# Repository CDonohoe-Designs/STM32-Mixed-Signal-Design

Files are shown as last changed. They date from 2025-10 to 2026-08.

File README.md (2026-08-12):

# STM32 Mixed-Signal Signal Generator & Analyser

I designed this project as a mixed-signal signal generation and acquisition platform based on the **STM32F103**. The system is designed to generate and analyse analogue signals over approximately **20 Hz–20 kHz** using external ADC and DAC signal paths.

The project focuses on the complete signal chain rather than the MCU alone: analogue input protection and conditioning, anti-alias filtering, ADC acquisition, DAC reconstruction filtering, analogue output buffering, bias generation, separate analogue/digital power supplies, USB-C and EMC/ESD considerations.

A major part of the work was understanding and documenting the engineering decisions behind each stage, including sampling requirements, filter design, signal biasing, noise, impedance and mixed-signal PCB architecture.

---

## Design Documentation

**[View Complete Mixed-Signal Design Report (PDF)](STM32-Mixed-Signal-Design/STM32-Mixed-Signal-Design.pdf)**

The design report is the main engineering document for this project and covers:

- System architecture and requirements
- Sampling-rate and ADC/DAC considerations
- Analogue front-end design
- Input protection and RF filtering
- Anti-alias filtering
- DAC reconstruction filtering
- Sallen-Key filter design
- Mid-supply analogue bias generation
- Separate analogue and digital power architecture
- USB-C, ESD and EMC considerations
- STM32F103 implementation
- STM32CubeIDE configuration
- Schematic design and component selection

---

## System Architecture

The system combines signal generation and signal acquisition around the STM32F103:

**Analogue Input → Protection / Filtering → Analogue Front End → ADC → STM32F103**

**STM32F103 → DAC → Reconstruction Filter / Buffer → Analogue Output**

The power architecture uses separate supplies for the analogue and digital sections, with a switching regulator used for the digital circuitry and a low-noise LDO used for the analogue circuitry.

---

## Key Design Areas

### Analogue Front End

The input signal chain includes protection, filtering, buffering and signal conditioning before the ADC.

The analogue input is biased around a mid-supply reference to allow bipolar AC signals to be processed by the single-supply analogue circuitry.

### ADC / DAC

External ADC and DAC devices provide the analogue acquisition and signal-generation paths.

The design considers:

- ADC resolution and sampling rate
- Nyquist requirements
- Input impedance
- ADC drive requirements
- Anti-alias filtering
- DAC reconstruction filtering
- Output buffering

### Power

The power architecture separates the requirements of the digital and analogue circuitry:

- Switching regulation for the digital section
- Low-noise LDO regulation for the analogue section
- Input filtering
- Decoupling
- Mid-supply analogue bias generation

### USB-C

USB-C provides the external power/interface connection.

The design includes:

- USB-C connection
- ESD protection
- Data-line filtering
- Common-mode filtering
- Power-input filtering

---

## Development Tools

- **Altium Designer** — schematic and PCB design
- **STM32CubeIDE** — STM32 configuration and embedded development
- **LTspice** — analogue and filter analysis
- **Git / GitHub** — project documentation and version control

---

## What This Project Demonstrates

This project demonstrates my approach to **mixed-signal hardware design**, particularly the interaction between analogue signal conditioning, ADC/DAC conversion, embedded processing and power architecture.

The main engineering focus is on understanding the complete signal path:

**input protection → analogue conditioning → filtering → conversion → processing → signal generation → analogue output**

rather than treating the MCU, ADC, DAC and analogue circuitry as independent blocks.

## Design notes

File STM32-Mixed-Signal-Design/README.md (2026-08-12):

# STM32 Mixed-Signal Signal Generator and Signal Analyser

This is my STM32-based mixed-signal design for a compact signal generator and signal analyser.

I designed this board to show how a small embedded system can generate analogue test signals, capture external analogue signals, and handle the practical mixed-signal design issues that come with ADCs, DACs, USB power, filtering, biasing, EMC protection and PCB layout.

My design uses an STM32 microcontroller as the main controller, with a DAC output path for signal generation and an ADC input path for signal measurement. The DAC side is used to generate low-frequency analogue waveforms, while the ADC side allows an external signal to be conditioned, filtered and sampled for analysis.

The target signal range is approximately 20 Hz to 20 kHz, so the project is aimed at low-frequency / audio-band signal work rather than high-speed RF. I included analogue front-end circuitry, anti-aliasing and reconstruction filtering, bias generation for single-supply operation, USB-C power input, ESD protection, and separate analogue/digital supply filtering.

At a high level, my design works as:

- **Signal generator:** the STM32 controls the DAC, creating an analogue output signal through a filtered output stage.
- **Signal analyser:** an external analogue signal enters through the input connector, passes through protection and analogue conditioning, and is then sampled by the ADC.
- **Mixed-signal PCB example:** the board brings together digital control, analogue signal paths, power regulation, USB, filtering, grounding and EMC considerations in one small design.

I created this project as a portfolio piece to demonstrate practical mixed-signal hardware design, from system requirements and schematic capture through to converter selection, analogue filtering, power-supply design and PCB implementation.

## Contact
**Caoilte Donohoe** · Dublin, Ireland  
Email: caoiltedonohoe@gmail.com · LinkedIn: https://www.linkedin.com/in/caoilte-donohoe-69601a40a/ · GitHub: [CDonohoe-Designs](https://github.com/CDonohoe-Designs)

---
© 2025 Caoilte Donohoe. All rights reserved.

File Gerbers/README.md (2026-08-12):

Gerber manufacturing files for STM32 Mixed-Signal Design.

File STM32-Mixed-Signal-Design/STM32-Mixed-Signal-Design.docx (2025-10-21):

STM32 Mixed Signal Design:

Description:

The purpose of the presentation is to show the design considerations for a mixed signal board. The design contains low-frequency analog and high-frequency digital design elements on a 4-layer FR4 PCB. It will also include system-level design, component selection, analogue (e.g. op-amps, filters, ADC/DAC interfaces), digital (e.g. microcontrollers, USB), and power supply (e.g. switching converter) circuitry design, simulation, and schematic capture.

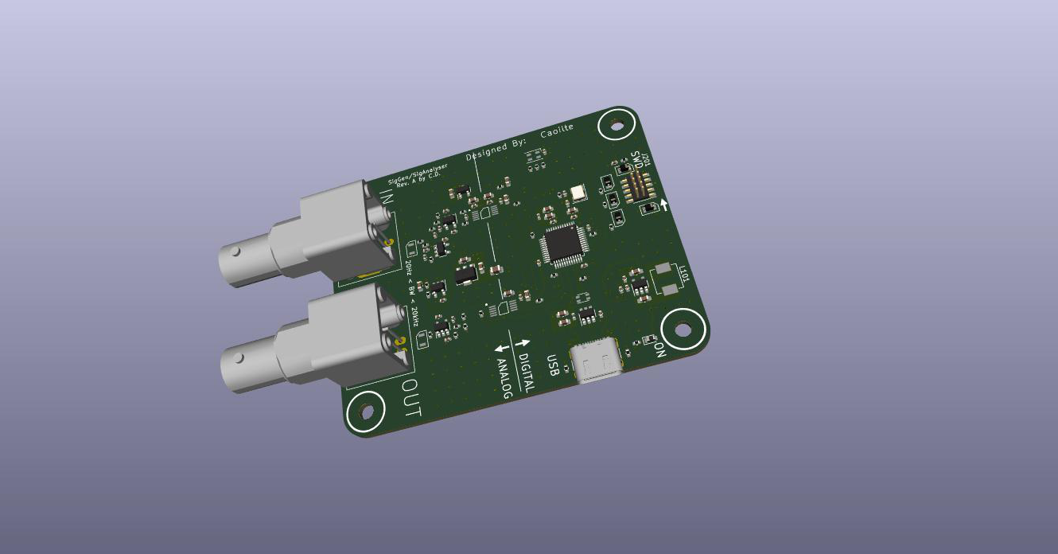
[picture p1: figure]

SYSTEM REQUIREMENTS:

USB

- The design is low-frequency (or low-bandwidth), 20 Hz to 20kHz approximately.
- The Max frequency of interest is 20kHz, so due to Nyquist, I need to sample at double the maximum frequency of interest.
- Sampling rate at least 40kHz.
- To reduce quantisation error and get accurate readings I will need an ADC with a minimum bit depth of 12.
- Single channel data-rate: I Channel x 12 bits x 40,000 samples per second (fs=40kHz) = 0.46 Mbit/s
- USB 2.0 with• FS: up to 12 Mbits/s and HS: up to 480 Mbits/s → FS is more than sufficient!
- The system is a bus-powered device only (not acting as a host), therefore far less than 500mA current consumption.
- I Choose USB Type C as it is the newest tech.

POWER SUPPLIES

Split digital and analogue supplies.

Digital: switching supply for efficiency, digital is far more tolerant of noise. This digital circuit digital draws 100s of mAs maximum.

Analog: linear (LDO) regulators for improved noise performance. Analog circuitry typically draws less current (10s of mAs maximum) → regulator efficiency is not much of an issue.

Input power from USB.

- (Very) noisy power rail → Requires adequate filtering.
- Nominally +5V. Can go as low as +4.5V → Watch out for regulator drop-out voltages!
- 150mA approx.

Analog Sections:

For ADC:

• High-impedance (>I MOhm?) input buffer with ESD protection, RF filtering.

• Anti-aliasing filter with a cut-off at (max.) half the ADC sampling rate (Nyquist limit).

For DAC:

• Low-impedance (-50 Ohm?) output buffer with ESD protection to drive loads.

• Anti-aliasing filter with a cut-off at (max.) half the DAC sampling rate (Nyquist limit).

MISCELLANEOUS

Mechanical

• PCB dimension constraints, mounting holes, connector placement, which case are we designing for (conductor?)?

Connectors

• Debugging interface, input/output connector types (SMA, BNC, etc...).

Peripherals

• LED to indicate power on, LED(s) connected to MCU for status information.

Other

• Timing (crystal frequencies, types, etc...).

• ESD protection and filtering for EMC.

• Biasing for single-supply analogue circuitry.

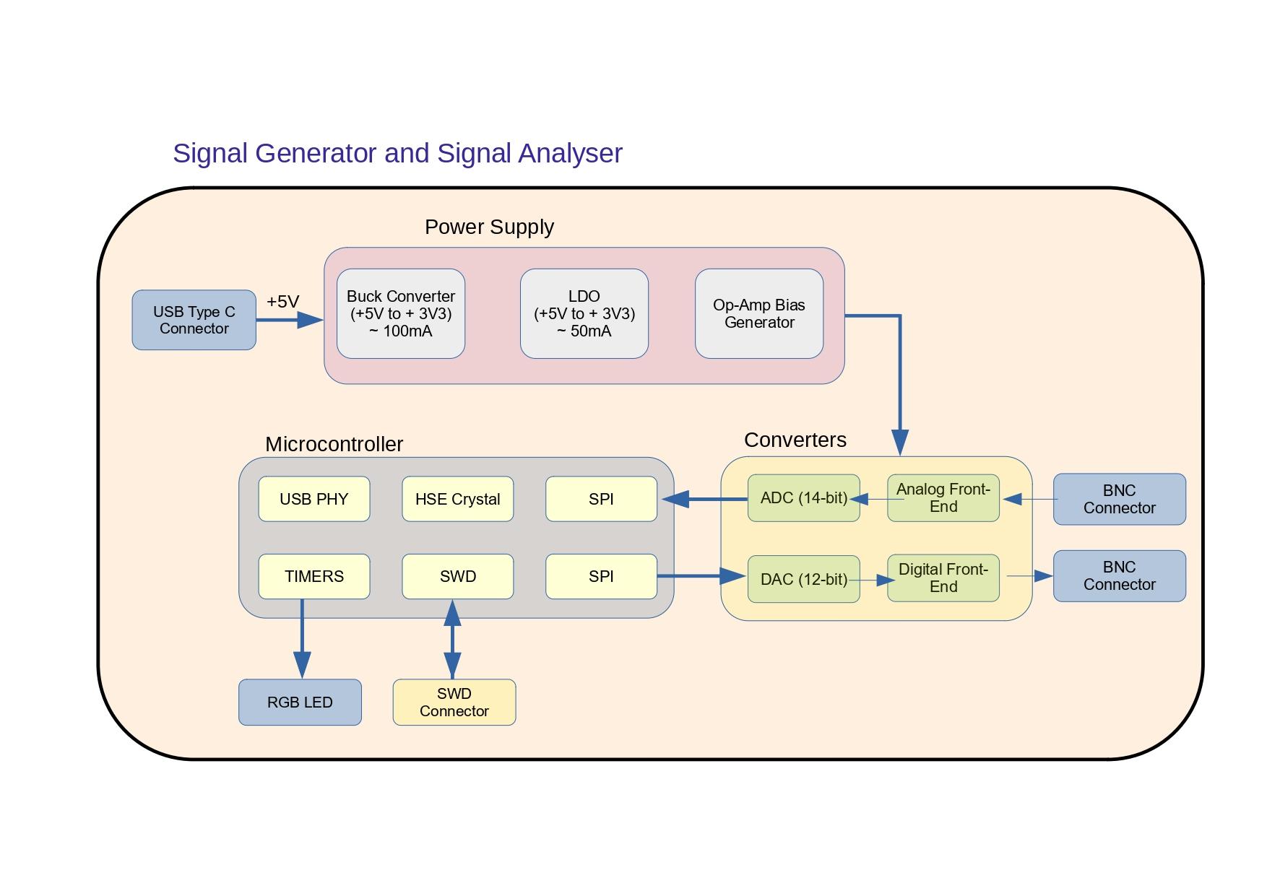
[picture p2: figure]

Schematic Capture:

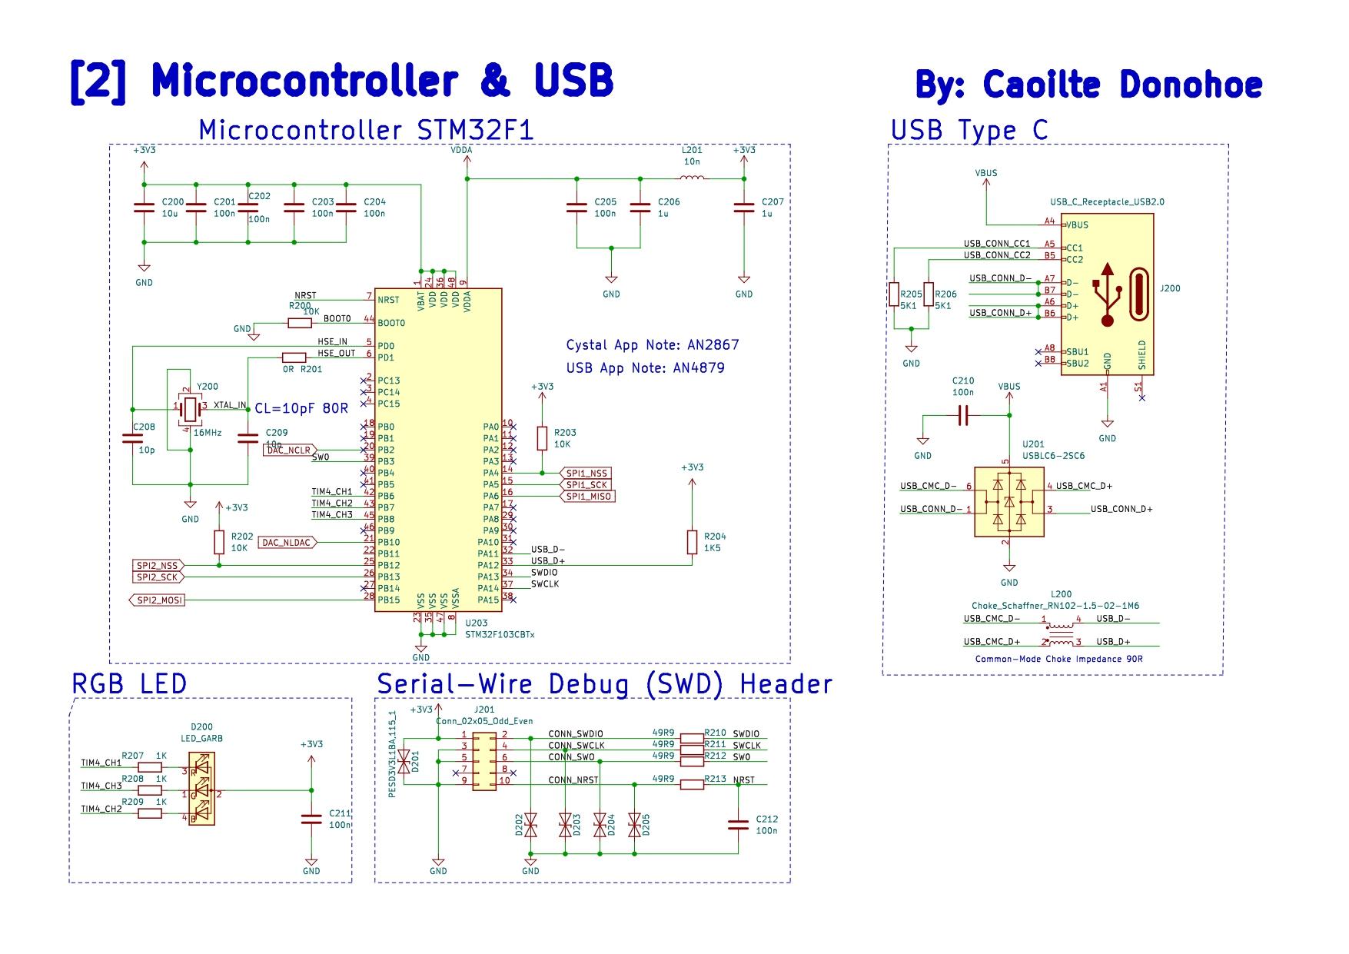
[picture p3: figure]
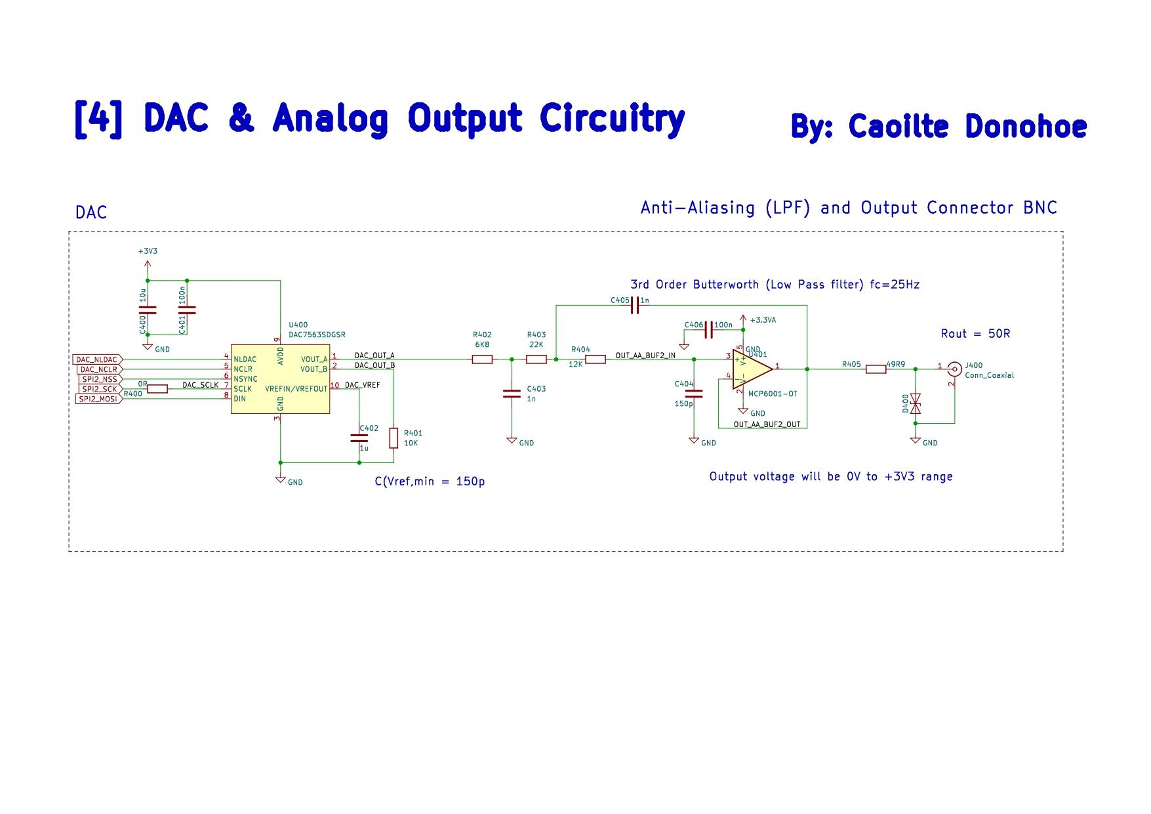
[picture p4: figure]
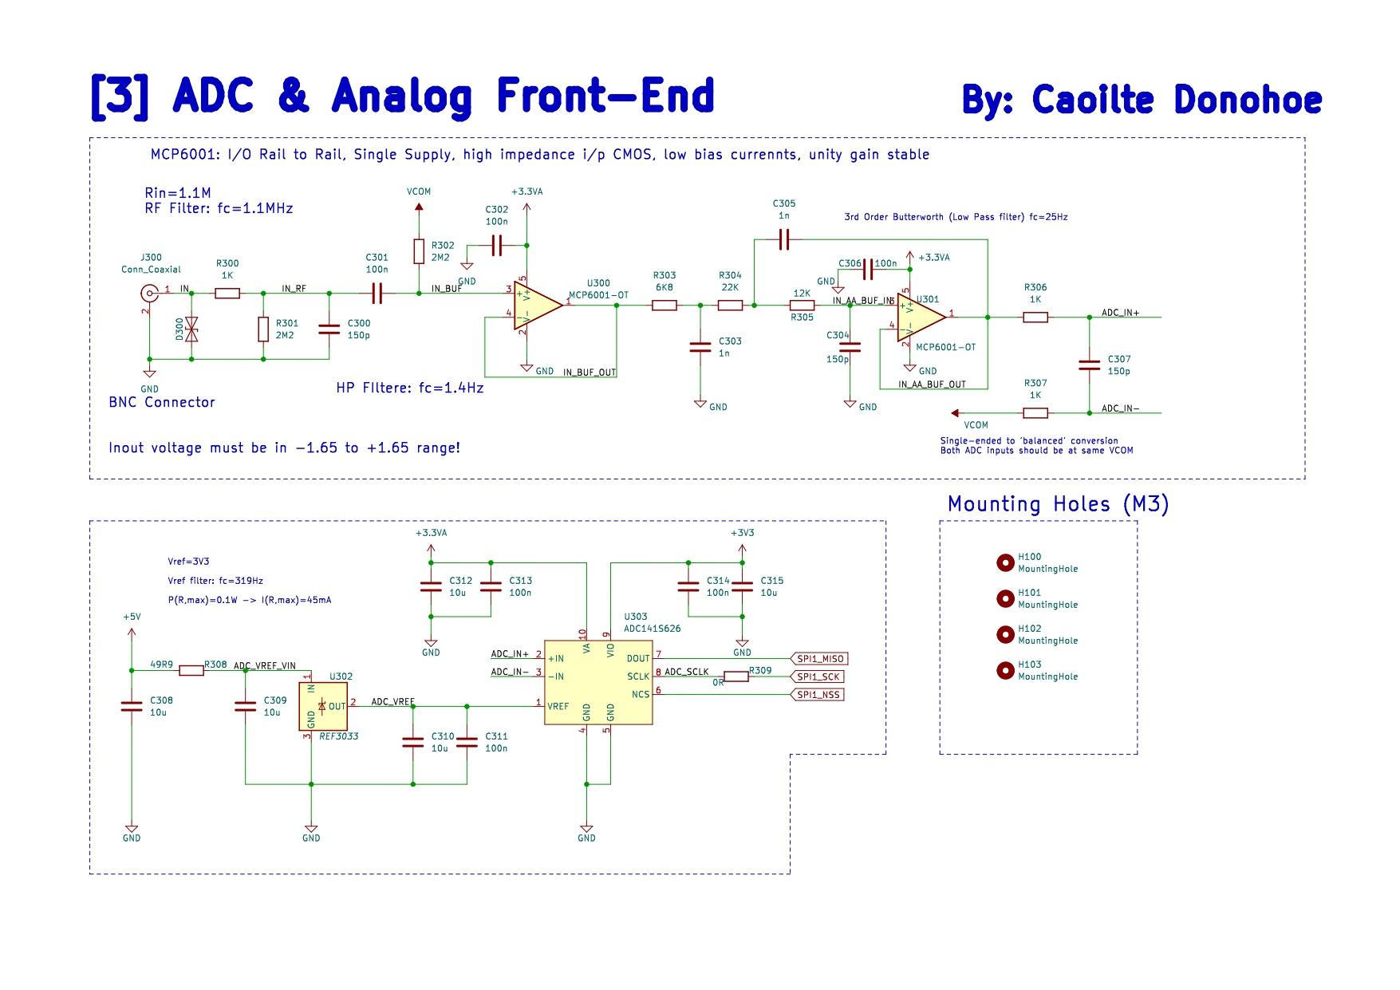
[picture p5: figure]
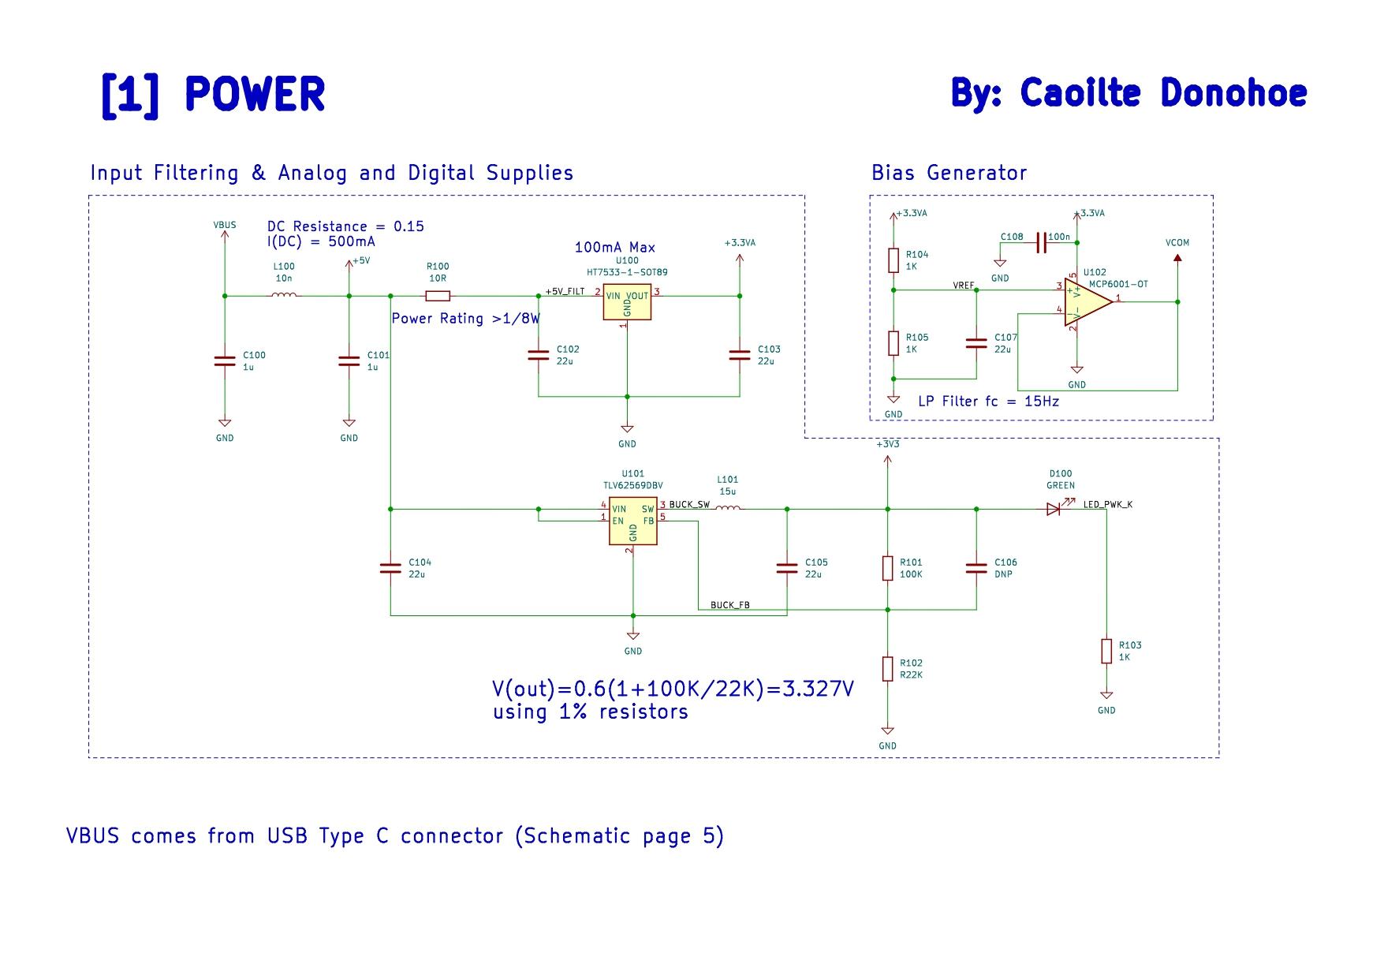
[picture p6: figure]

Schematic Design:

INPUT FILTER/LDO regulator

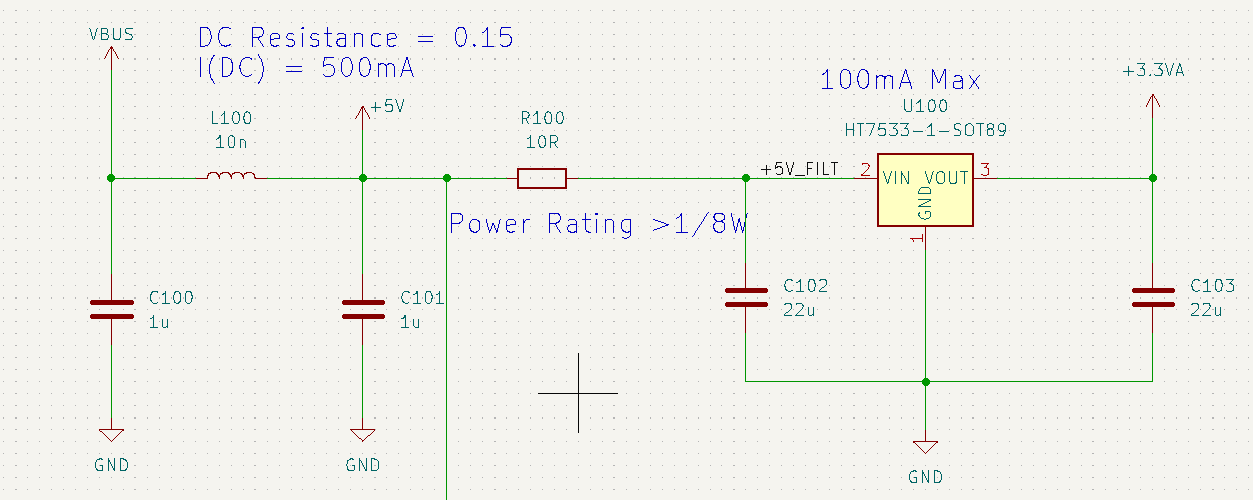
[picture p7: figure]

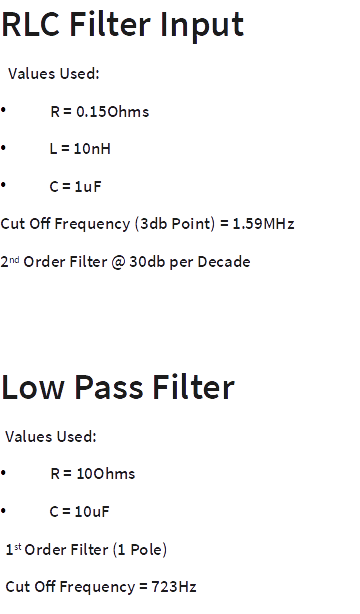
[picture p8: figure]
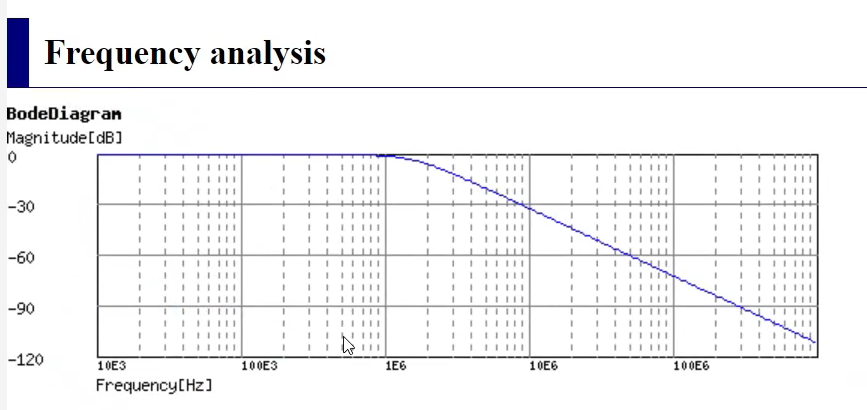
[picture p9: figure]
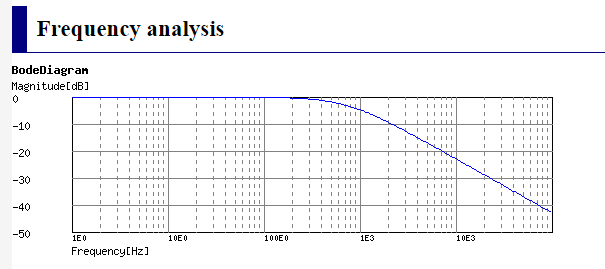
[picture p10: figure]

INPUT FILTER/LDO regulator

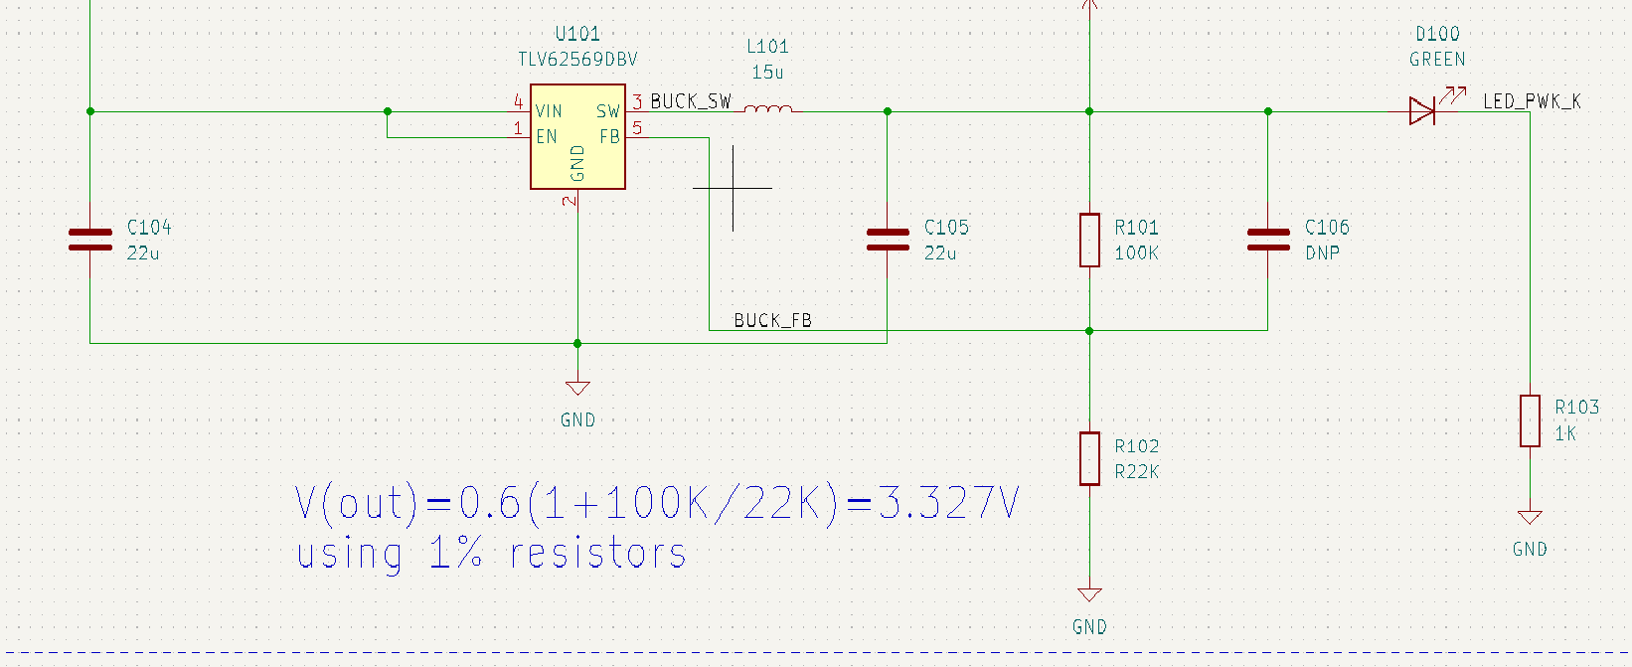
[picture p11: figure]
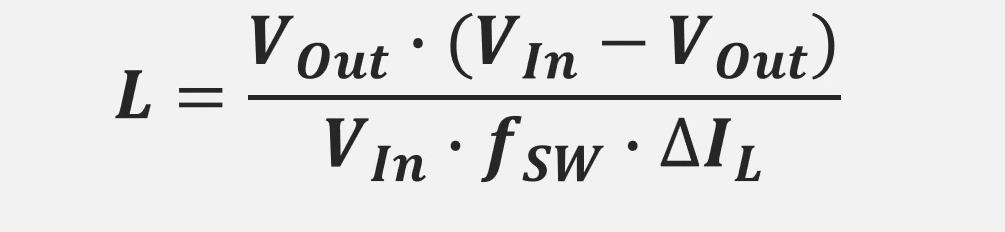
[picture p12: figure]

Inductor Calculations:

Vout = +3V3, Vin = 5V

fsw = 1.5MHz and Imin = 55mA

IL = 0.25 x 0.25A =0.1375

Therefore L = 68uH

BIAS GENERATOR:

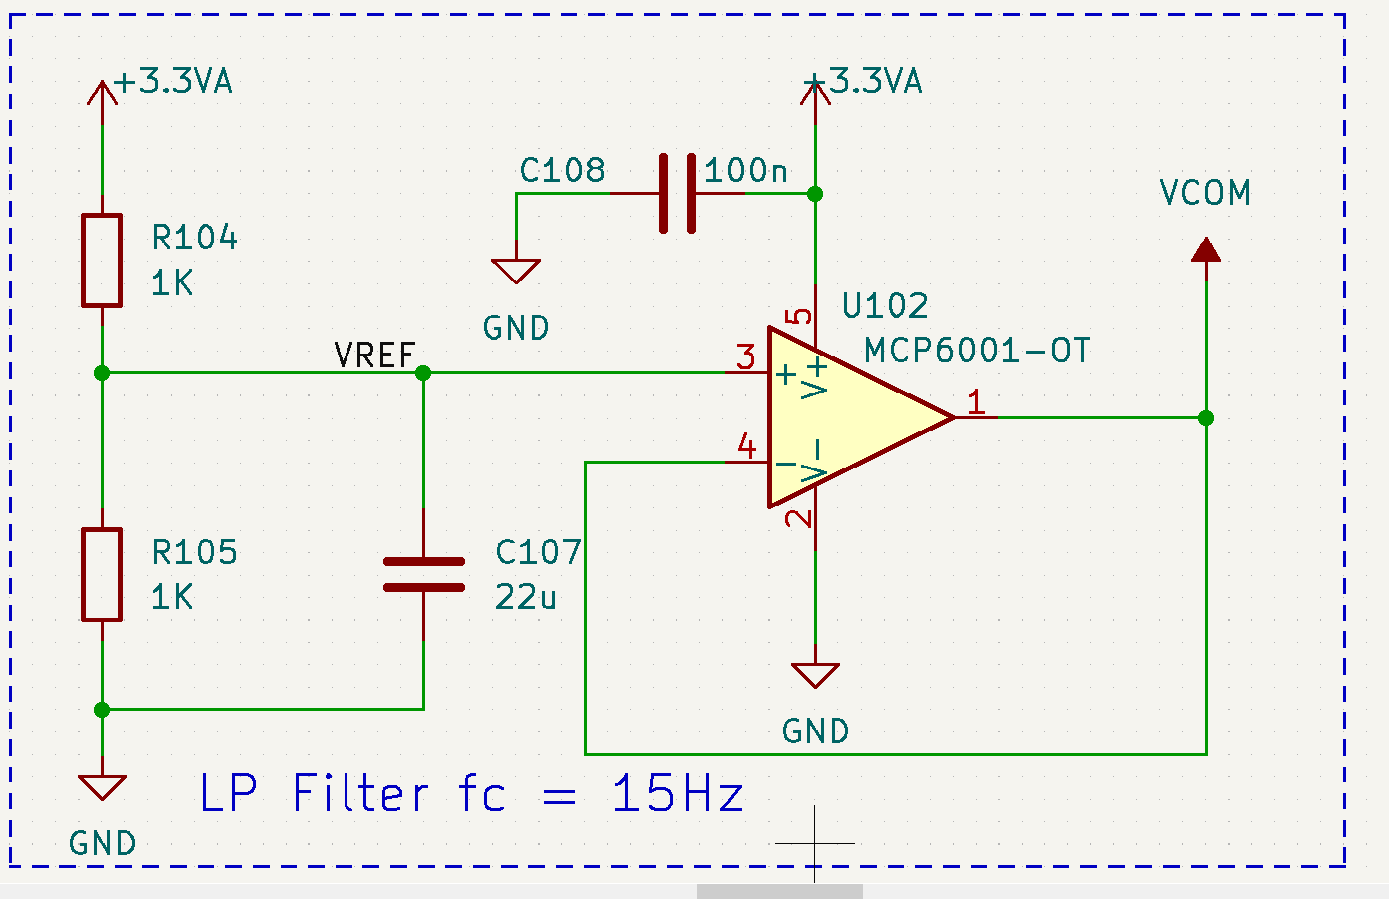
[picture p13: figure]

- Biased at VCC/2 to allow for FSD
- AC Signals are coupled onto Bias Gerator vial coupling caps
- Low Pass Filter via R105 and C107
- 3dB bandwidth = 15Hz

MICROCONTROLLER STM32F103:

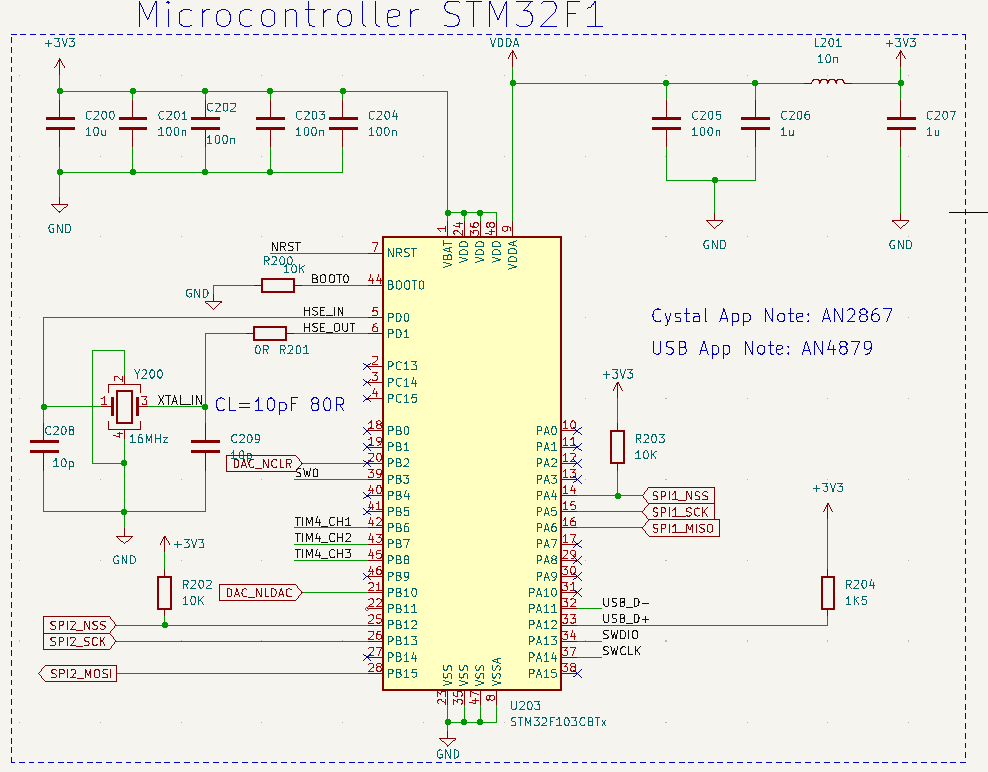
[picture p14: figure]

Pin Configuration and Function Assignment in STM32CUBEIDE

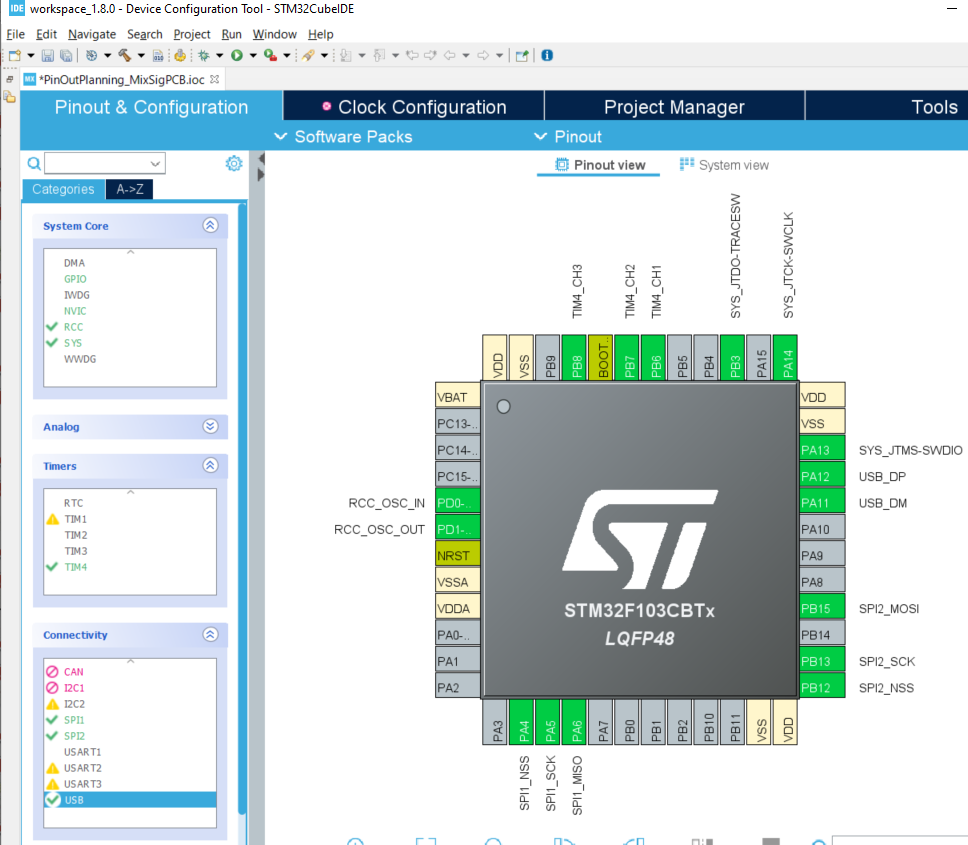
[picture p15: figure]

USB, ESD Protection and Filter for EMC:

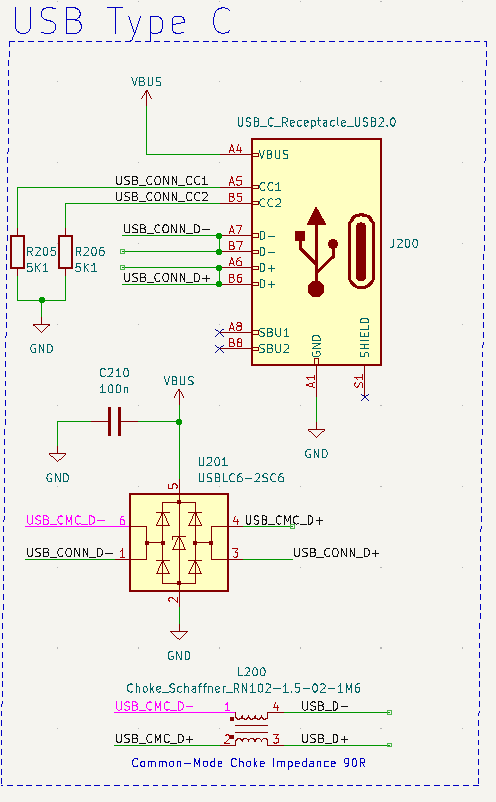
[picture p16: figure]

- STM32F103 requires 1.5k pull-up on D+ Line - USB supply is noisy → Adequate filtering! RLC - Add ESD protection - Data Line Filtering → Optional via common mode choke to improve EMC performance - Tie CC1 and CC2 to ground for 5V 500mA power - ESD via Bi-Directional TVS diode

ADC and Analog Front-End:

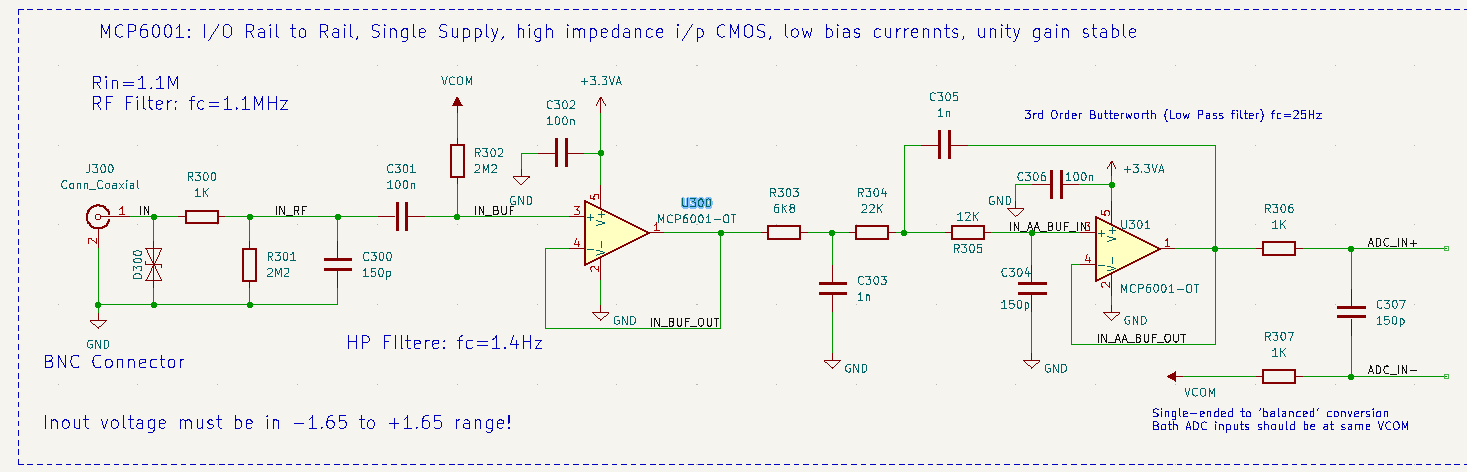
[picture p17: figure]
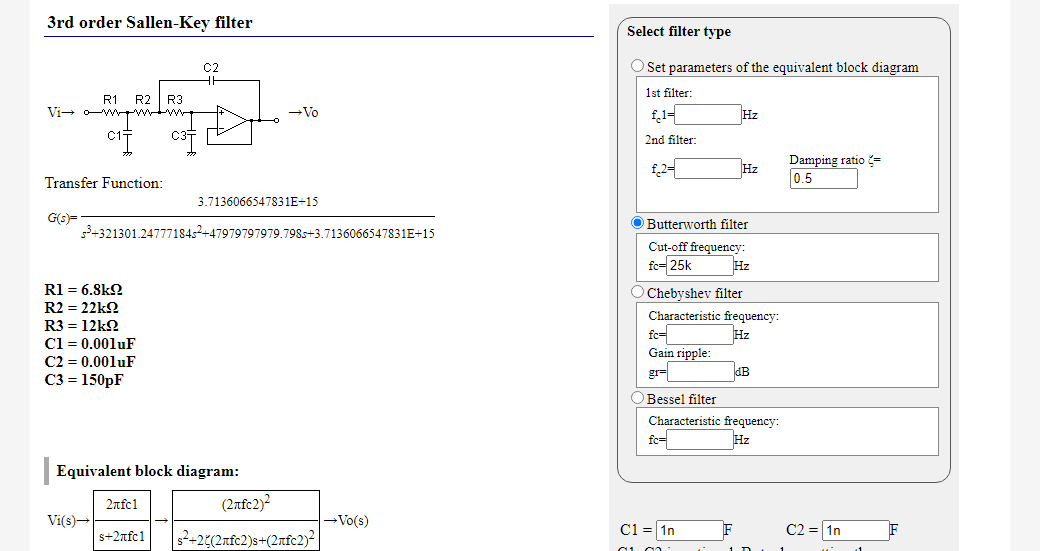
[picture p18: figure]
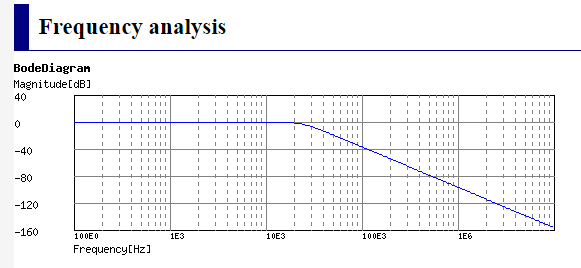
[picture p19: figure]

ADC Circuit:

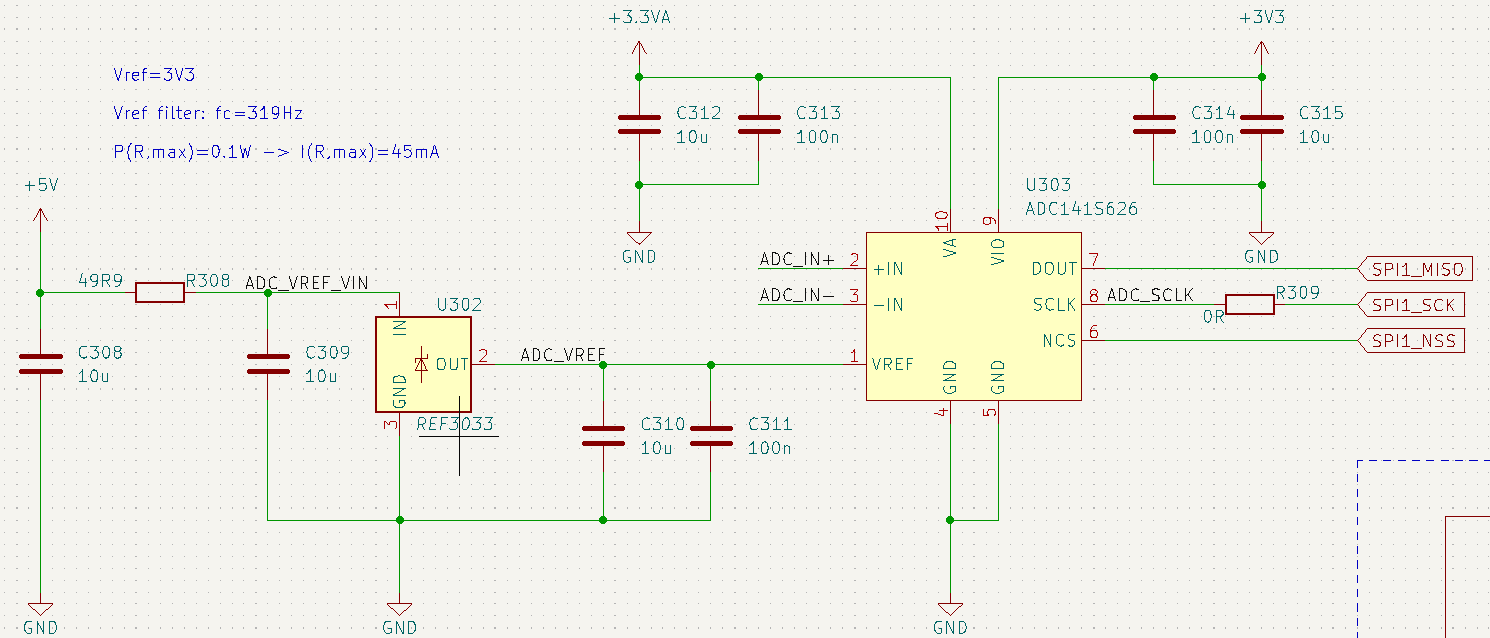
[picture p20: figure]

Key parameters:

Resolution (Bits) 14 Number of input channels: 1 Sample rate (Max) (kSPS): 250 Interface type : SPI Architecture: SAR

Key parameters:

Resolution (Bits): 12 Number of DAC channels: 2 Interface type: SPI

Output type: Buffered Voltage Features: Low Power, Reset to Mid-Scale, Small Size

ADC Circuit:

Q. Vref why use it?

A. To give more stability over temp and far greater accuracy and lower noise that ldo reg

Q. R308 what is it used for?

A. It is used to limit the current to I i/p max of 45mA

Q. What is R309 used for?

A. This can be placed with a slightly higher value to reduce ringing and improve EMC.

Note: Use Analog supply voltage for Analog side. Use Digital Supply for digital supply. The IC is split in half, the analog pins to the left and the Digital pins to the left.

Also do not split the ground pins. They should be on the same plane

Analog Front-End: First stage

Q. What is the TVS diode for?

A. The TVs diode is used to protect the circuit from ESD. It is bi Directional as the signal swings between +ve and -ve

Q. Input filter is it high pass or low pass and what are the components used?

A. The input filter uses R300 and C300 as a low pass filter with a cut-off freq 1.1MHz from say FM radio or WiFi etc

Q. Calculate the I/p impedance

A. I/p impedance is the parallel of R301 and R302 or 2.2Meg || 2.2Meg or 1.1 Meg

Q. What is C301 used for?

A. It is an AC coupling cap or dc decoupling cap. +1.65V to -1.65V

Q. What is Johnson Noise?

A. High-value resistors in the source path generate noise. Keep these values low. R301 and R302 are not in the path but parallel to it i.e. they have a path to ground.

Q. What is Vcom?

A. Vcom is the DC bias voltage. It is set to be half the Vcc or 1.65V. This allows an AC signal of +1.65v to -1.65 volts

Q. Describe the op-amp?

A. CMOS op-amp, high impedance i/p, low impedance o/p, unity gain, voltage follower. With CMOS op-amps you have low i/p bias currents. High Z so it won't load the sensor or i/p.
B. It reduces aliasing artefacts due to sampling.

Second Stage: Sallen Key

Q. What are its features?

A. 3rd order (3 caps) Butterworth filter, LPF , maximally flat, unit gain LPF

Q. What is its function?

A. To prevent aliasing therefore an anti-aliasing filter.

Q. Controlled impedance over what conditions?

A. Over frequency, the impedance of the circuit would fluctuate. With an active filter, this won't happen.

Q. Why choose lower-value resistors?

A. You get Johnson noise with high-value resistors that are in the signal path. Calculate passive components with higher value caps in C305 and C306 (1nF). The values for resistors will be lower.

ADC Circuit:

Q. Where is the Voltage Ref?

A. The voltage ref is built in

Q. Explain the filter?

A. Filter Salen key is the same as ADC but its a reconstruction filter

Q. What is the output of the op-amp

A. Output from DAC is analog and it biases the the op-amp. So it will be from 0 to 3.3V as it is rail to rail.

Q. What is R405 used for?

A. The output from the op-amp is very low and unstable so it defines the output impedance

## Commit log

2026-05-12 Add PDF version of STM32 mixed-signal design
2026-05-12 Add PDF version of STM32 mixed-signal design note
2026-06-29 Create Gerbers
2026-06-29 Add files via upload
    Added gerbers
    [SigGen_SigAnalyser-B_Cu.gbr, SigGen_SigAnalyser-B_Mask.gbr, SigGen_SigAnalyser-B_Paste.gbr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]
